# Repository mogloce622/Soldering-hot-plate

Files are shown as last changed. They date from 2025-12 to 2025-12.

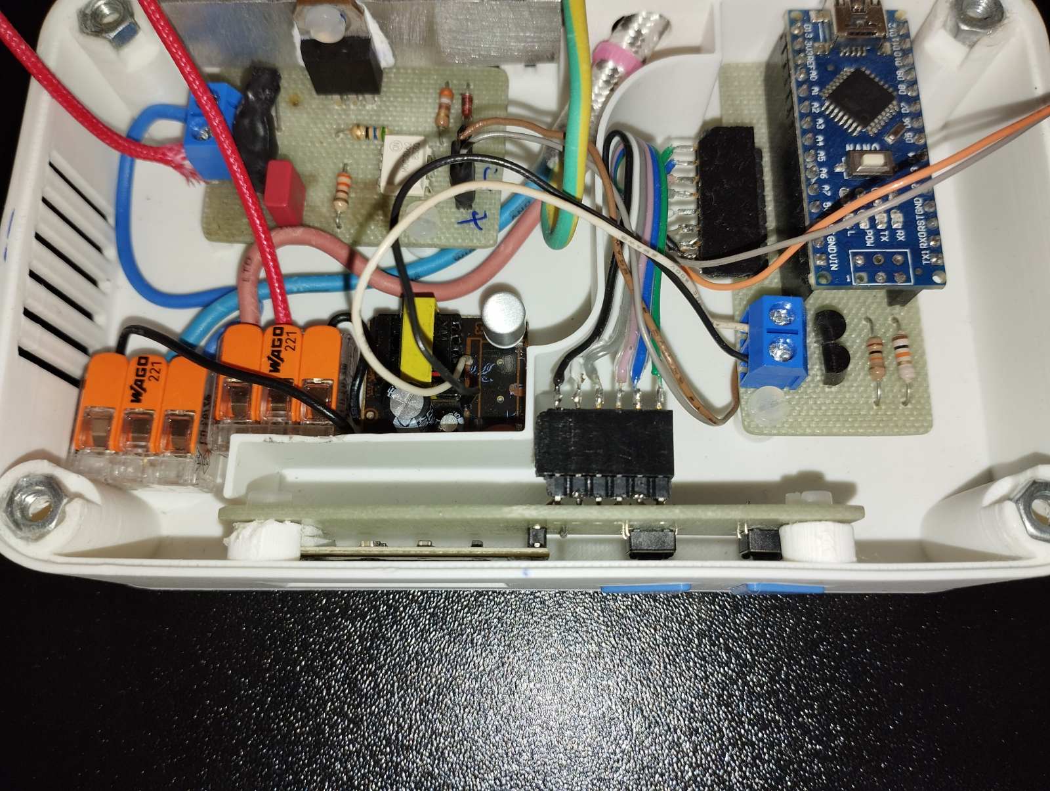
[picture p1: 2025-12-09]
pictures/6.jpg

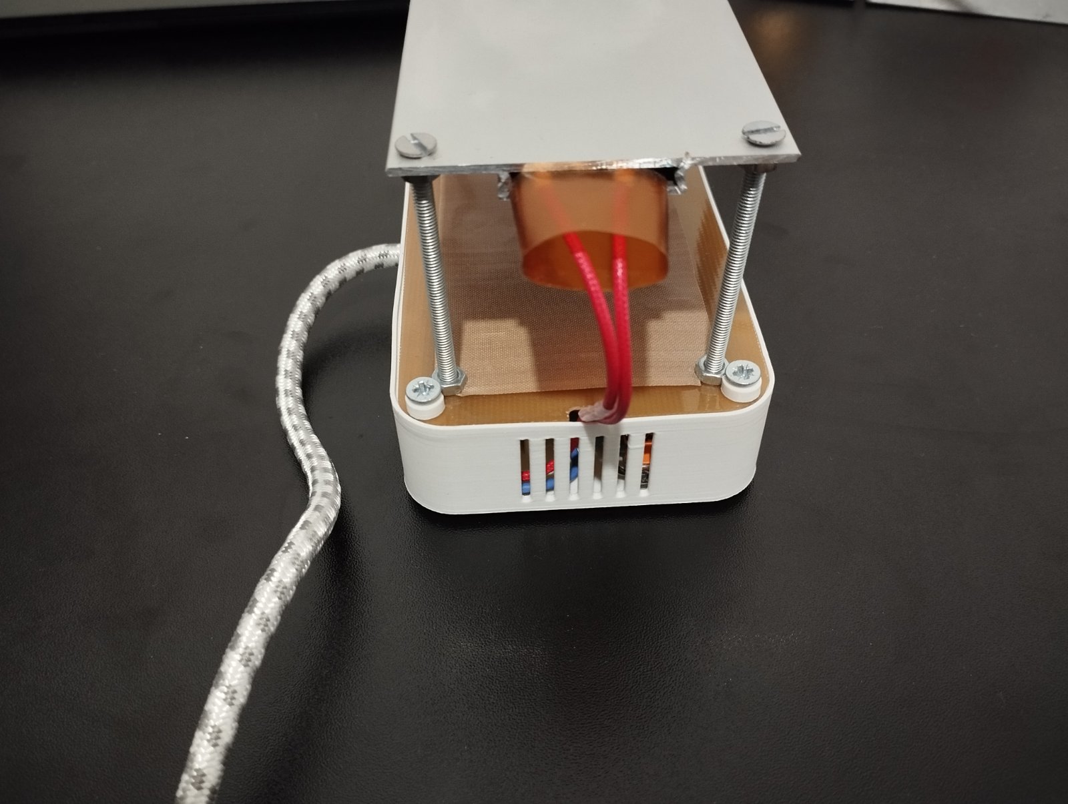
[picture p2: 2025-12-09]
pictures/14.jpg

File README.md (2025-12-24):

This is my hot plate, which has two temperature curves: one for leaded solder paste (183 °C) and one for lead-free paste. It consists of a 400 W 220 V PTC heating plate that is spaced 5.5 cm from the enclosure using screws. The temperature is measured using a 100 k NTC sensor taken from cheap Chinese food thermometers (TP-101). The heating plate is also grounded as shown in the picture and all printed parts are printed using PLA.

If you want buzzer, solder it to pin 8.

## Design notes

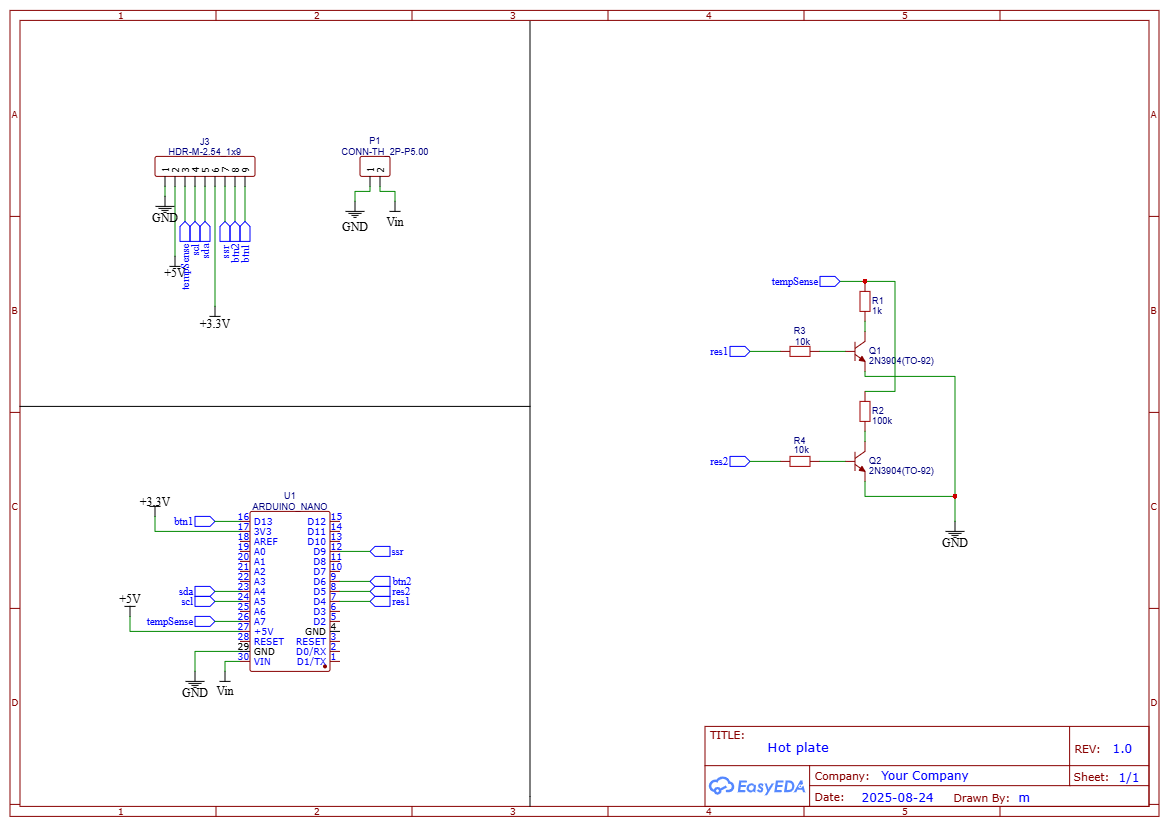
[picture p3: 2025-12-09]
schematic/Hot_plate.png

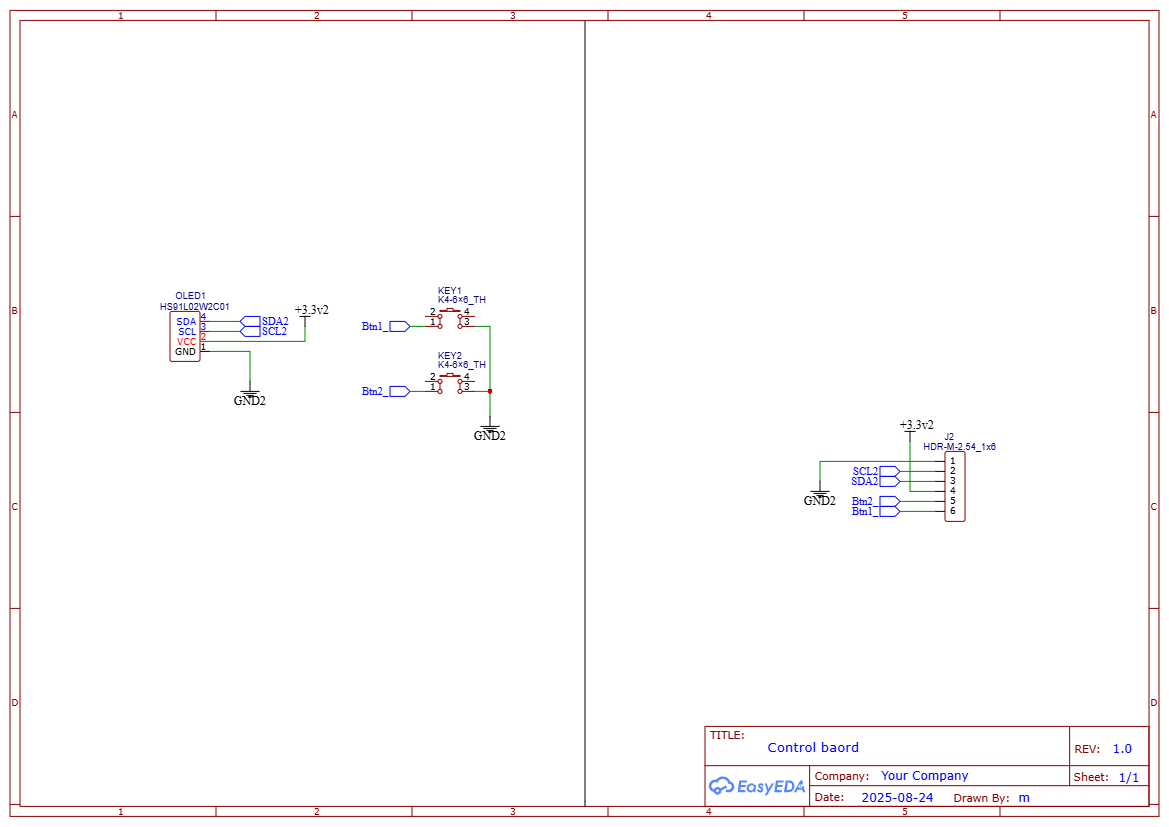
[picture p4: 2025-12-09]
schematic/Control_board.png

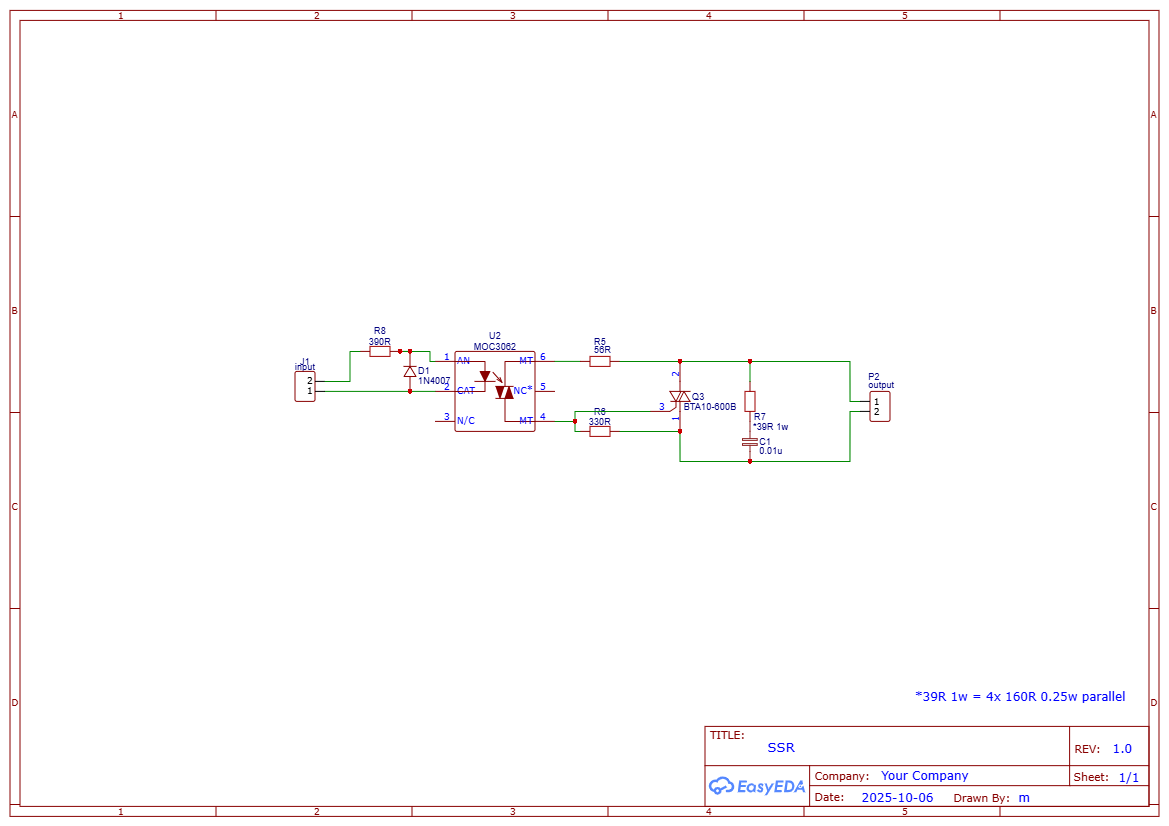
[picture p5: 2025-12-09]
schematic/Ssr.png

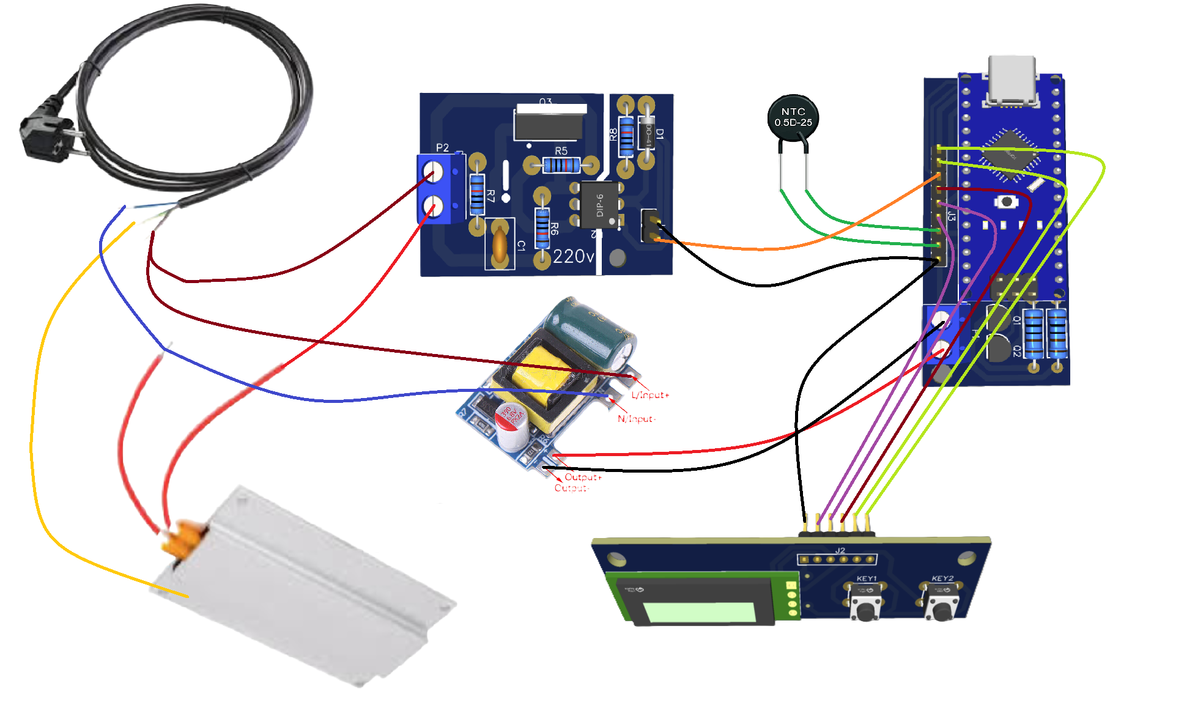
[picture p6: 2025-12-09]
Circuit diagram.png

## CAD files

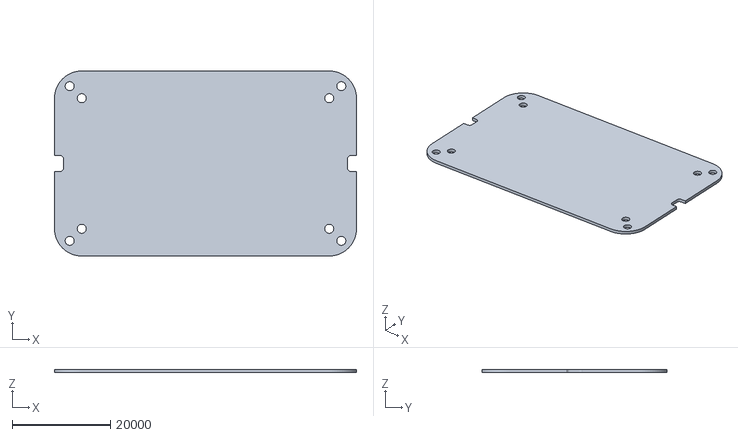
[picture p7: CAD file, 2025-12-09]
3dModels/topCover.dxf
61401.6 x 37625.8 x 692.5

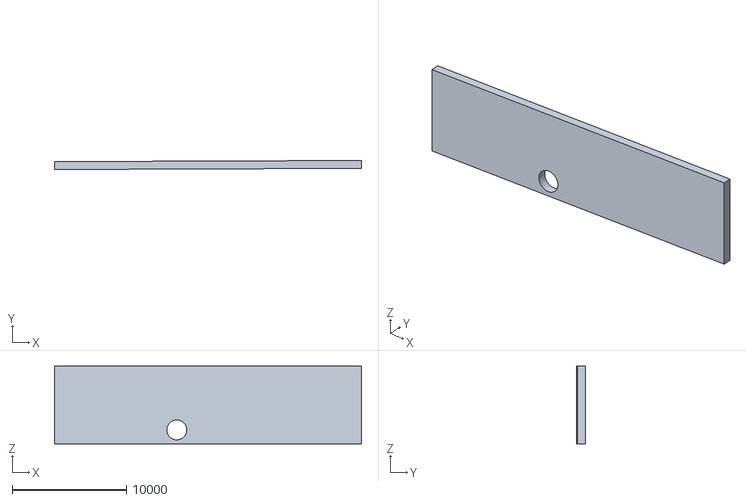
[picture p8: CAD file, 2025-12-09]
3dModels/cooler.dxf
26870.4 x 792.6 x 6823.4

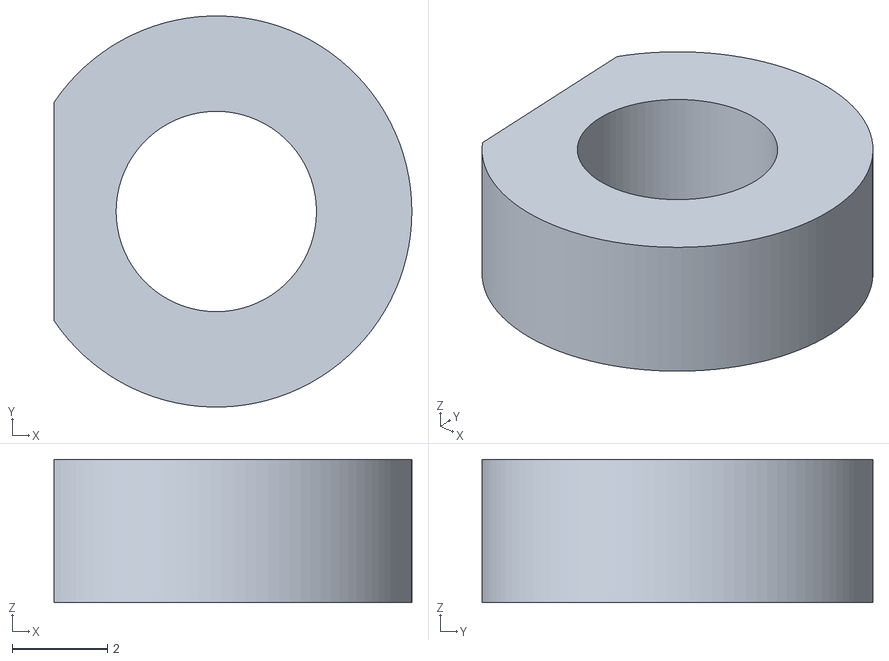
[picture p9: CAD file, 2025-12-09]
3dModels/spacer.stl
7.50 x 8.20 x 3.00

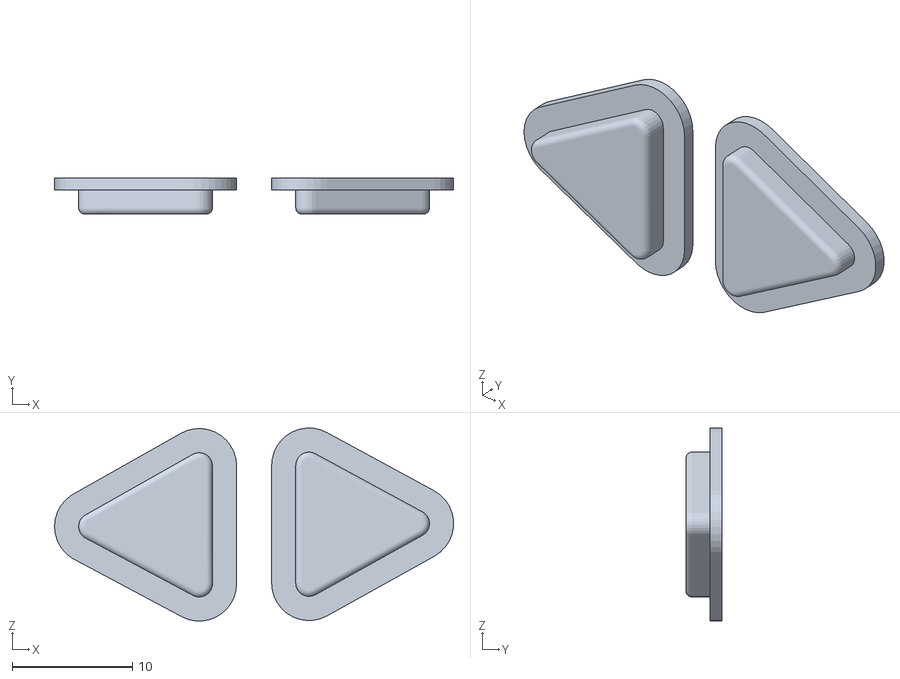
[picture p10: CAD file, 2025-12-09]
3dModels/Hot_plate_buttons.stl
33.1 x 3.00 x 16.0

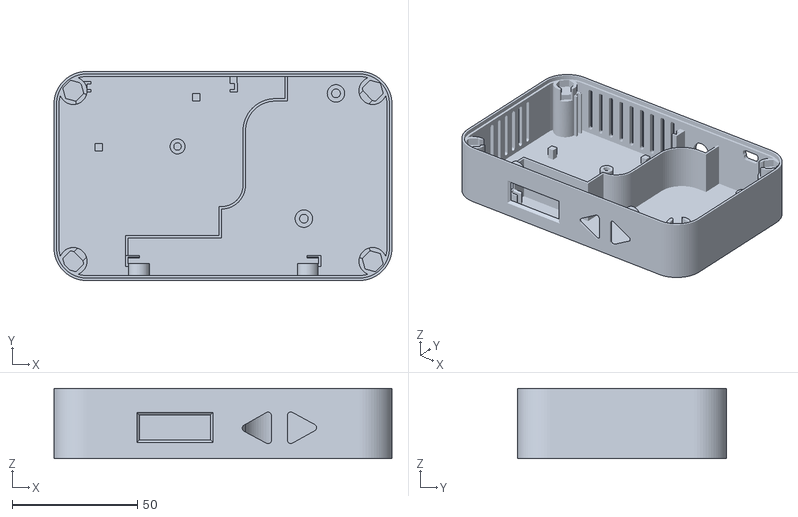
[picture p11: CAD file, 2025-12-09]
3dModels/hot plate.stl
135.0 x 83.5 x 28.0

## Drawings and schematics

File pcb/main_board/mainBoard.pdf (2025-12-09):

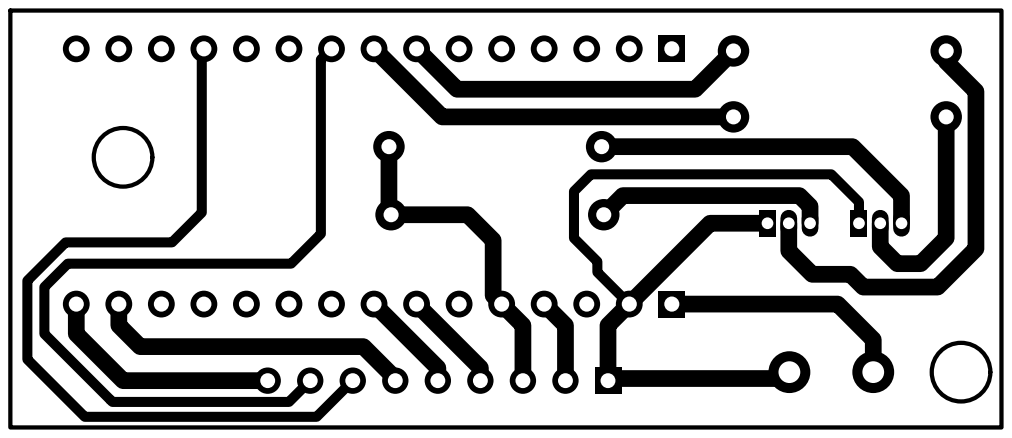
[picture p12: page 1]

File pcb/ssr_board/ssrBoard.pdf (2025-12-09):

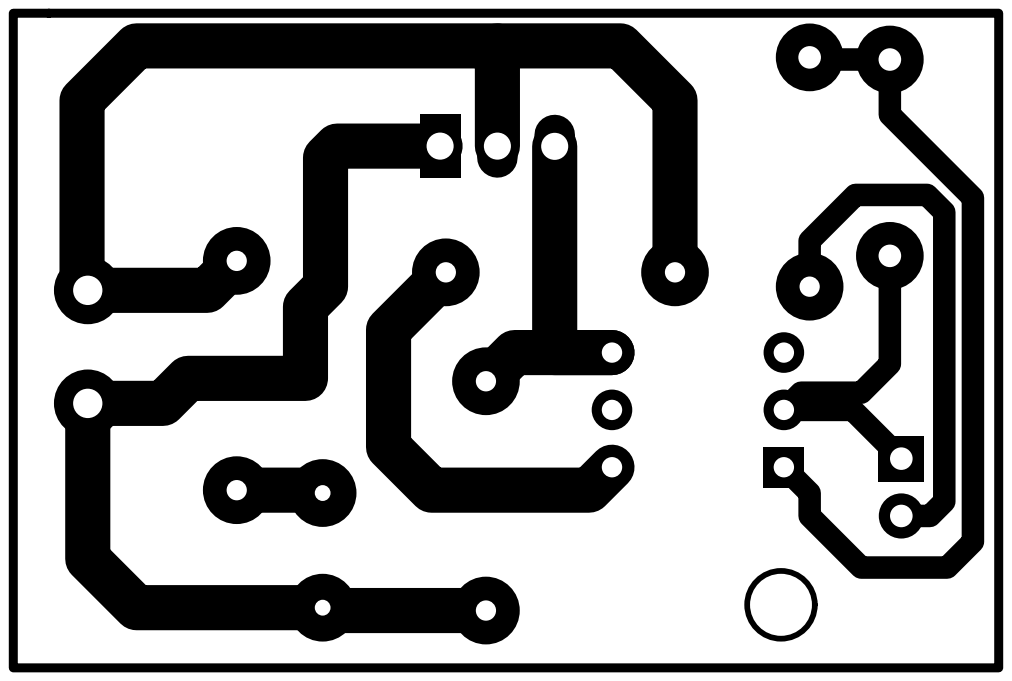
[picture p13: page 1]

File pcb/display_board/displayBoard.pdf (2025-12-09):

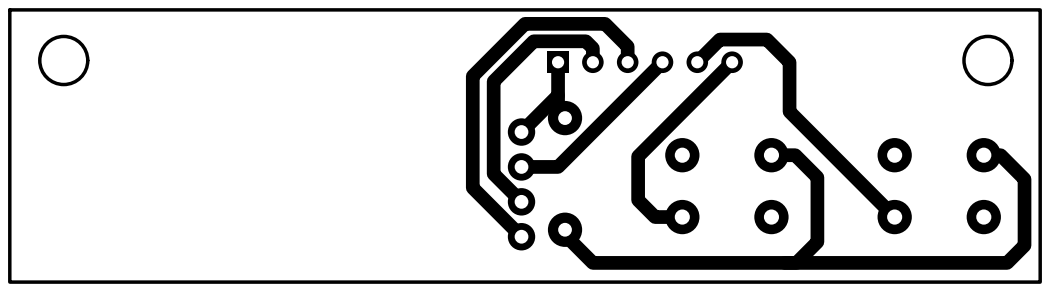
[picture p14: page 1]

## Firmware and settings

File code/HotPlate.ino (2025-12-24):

#include <Wire.h>
#include <Adafruit_GFX.h>
#include <Adafruit_SSD1306.h>
#include <PID_v1.h>
#include "InterpolationLib.h"
#include <Fonts/Org_01.h>
#include "anim.h"

#define SCREEN_WIDTH 128
#define SCREEN_HEIGHT 32
#define OLED_RESET     -1
#define SCREEN_ADDRESS 0x3C

#define temp 7
#define res1 4
#define res2 5
#define plate 9
#define buzzer 8

#define BTN_UP   6
#define BTN_DOWN 13

const double R0 = 100000.0;
const double T0 = 25.0 + 273.15;
const double BETA = 3950.0;
const unsigned long RES1 = 1000;
const unsigned long RES2 = 100000;
double RES = RES1;
static unsigned long lastSwitchTime = 0;
const unsigned long switchCooldown = 500;
const int numValues = 21;
//double tHot[numValues] = { 20.2, 25, 40, 60.2, 80.2, 90, 100, 110, 120, 130, 140, 150, 160, 170, 180, 190, 200, 210, 220, 230, 240 };
//double errorValues[numValues] = { 2.50,  0.50,  0.07, -0.20, -2.10, -2.40, -3.40, -5.07, -3.80, -5.53, -8.53, -9.05, -11.33, -11.75, -15.75, -18.40, -22.24, -24.48, -26.87, -30.75, -31.45 };

unsigned long lastMillis = 0;
const int samples = 40;
int s = 0;
const int thr = 110;
bool wRes = false;
double sumTemp = 0.0;
double sumRes = 0.0;
double avgTemp = 0.0;
double lastTemp = 0.0;
double avgRes = 0.0;
bool finished = false;
int safeTemp = 40;
int heatingState = 0;
int heatingProgress = 0;
bool heated = false;

double setPoint = 0, output = 0;
int mode = 0;
bool menu = false;
unsigned long previousMillis = 0;
int currentFrame = 0;
String modes[3] = {"HEAT", "LEAD", "NOLEAD"};
int modesSize = 3;
int menuPos = 0;
int curveTemp1[] = {145, 165, 225};
int curveTime1[] = {0, 70, 20};
int curveOffset1[] = {10, 0, 10};
int curveTemp2[] = {145, 180, 245};
int curveTime2[] = {0, 60, 15};
int curveOffset2[] = {10, 0, 10};
int arraySize = 3;
int curveStep = 0;
unsigned long holdStart = 0;
bool holding = false;
int targetTemp = 0;
int targetOffset = 0;
bool done = false;
bool ex = false;
bool buz = false;

//pid
double Kp = 4;
double Ki = 0.001;
double Kd = 90;

PID myPID(&avgTemp, &output, &setPoint, Kp, Ki, Kd, DIRECT);
Adafruit_SSD1306 display(SCREEN_WIDTH, SCREEN_HEIGHT, &Wire, OLED_RESET);

void setup() {
  Serial.begin(9600);
  pinMode(temp, INPUT);
  pinMode(res1, OUTPUT);
  pinMode(res2, OUTPUT);
  pinMode(buzzer, OUTPUT);
  digitalWrite(res1, HIGH);
  digitalWrite(res2, LOW);

  pinMode(BTN_UP,   INPUT_PULLUP);
  pinMode(BTN_DOWN, INPUT_PULLUP);

  delay(500);
  if(!display.begin(SSD1306_SWITCHCAPVCC, SCREEN_ADDRESS)) {
    Serial.println(F("SSD1306 allocation failed"));
    for(;;);
  }
  display.setRotation(2);
  display.clearDisplay();
  display.display();
  display.setTextColor(SSD1306_WHITE);
  display.setTextWrap(0);
  display.setFont(&Org_01);
  introAnimation();

  myPID.SetOutputLimits(0, 255);
  myPID.SetSampleTime(1000);
  myPID.SetMode(AUTOMATIC);
}

void loop() {
  unsigned long nowMillis = millis();

  if(buz) {
    digitalWrite(buzzer, HIGH);
    delay(200);
    digitalWrite(buzzer, LOW);
    buz = false;
  }

  //Button 
  String btn = getButtonAction();
  if(mode == 0 && menu == false) {
    if(btn == "up" || btn == "down" || btn == "select") { menu = true; btn = ""; }
  } 
  else if(mode > 0 && menu == false) {
    if(btn == "select") { menu = true; btn = ""; } 
    else if(btn == "exit") { setPoint = 0; targetOffset = 0; heatingState = 1; ex = true; curveStep = 0; }
    if(mode == 1 && menu == false) {
      if(btn == "up") { setPoint += 5; if (setPoint > 250) setPoint = 250; }
      else if(btn == "down") { setPoint -= 5; if (setPoint < 0) setPoint = 0; }
    }
  }

  if(mode > 0 && menu == false) {
    if(avgTemp > 40) heated = true;
    if(avgTemp < setPoint) heatingState = 2;
    else if(avgTemp >= setPoint && heated) heatingState = 1;
    else heatingState = 0;
    if((heated || ex) && avgTemp <= 40) { setPoint = 0; mode = 0; heatingState = 0; heated = false; done = false; holdStart = 0; ex = false; targetOffset = 0; }
  }

  if(menu == true) {
    if(btn == "select") { 
      if(mode != menuPos+1) { 
        setPoint = 0; 
        heated = false;  
        holding = false;
        curveStep = 0; 
        heatingProgress = 0; 
        targetOffset = 0; 
        done = false;
        holdStart = 0;
        ex = false;
        targetOffset = 0;
      } 
      mode = menuPos+1; 
      btn = "exit"; 
    }
    if(btn == "exit") { menu = false; menuPos = 0; }
    else if(btn == "up") { menuPos++; if(menuPos >= modesSize) { menuPos = 0; }}
    else if(btn == "down") { menuPos--; if(menuPos < 0) { menuPos = modesSize-1; }}
  } 

  if (mode > 1 && !done && !ex) {
    int curveTime = 0;
    if(mode == 2) {
      targetTemp = curveTemp1[curveStep];
      targetOffset = curveOffset1[curveStep];
      curveTime = curveTime1[curveStep];
    } else if(mode == 3) {
      targetTemp = curveTemp2[curveStep];
      targetOffset = curveOffset2[curveStep];
      curveTime = curveTime2[curveStep];
    }
    if (!holding) {
      setPoint = targetTemp+targetOffset;
      if (avgTemp >= targetTemp-2) {
        holding = true;
        holdStart = nowMillis;
      }
    }
    else {
      unsigned long holdTime = (unsigned long)curveTime * 1000UL;
      if (nowMillis - holdStart >= holdTime) {
        curveStep++;
        buz = true;
        holding = false;
        if (curveStep >= arraySize) {
          setPoint = 0;
          heatingState = 1;
          curveStep = 0;
          targetOffset = 0;
          done = true;
        }
      }
    }
    heatingProgress = map(curveStep, 0, arraySize, 0, 128);
  }

  static unsigned long lastPrint = 0;
  if (nowMillis - lastPrint >= 5000) {
    lastPrint = nowMillis;
    Serial.print(avgTemp, 1);
    Serial.print(",");
    Serial.println(setPoint, 1);
  }

  if(s < samples) {
    int adcValue = analogRead(temp);
    if (adcValue == 0) adcValue = 1;
    double resistance = RES * ((1023.0 / adcValue) - 1.0);
    double tempK = 1.0 / ( (1.0 / BETA) * log(resistance / R0) + (1.0 / T0) );
    double tempC = tempK - 273.15;
  
    sumTemp += tempC;
    sumRes += resistance;
    s++;
    delayMicroseconds(1000);
  }else finished = true;

  if (finished) {
    avgTemp = sumTemp / samples;
    avgRes  = sumRes / samples;
    if(lastTemp == 0) lastTemp = avgTemp;
    //if(avgTemp < tHot[0]) avgTemp += -0.152028912254266 * avgTemp + 9.81035163281709;
    //else avgTemp += Interpolation::ConstrainedSpline(tHot, errorValues, numValues, avgTemp);

    display.clearDisplay();
    if(menu == false) drawTemp(avgTemp, setPoint-targetOffset, mode, heatingState, heatingProgress);
    else drawMenu();
    display.display();

    sumTemp = 0.0;
    sumRes  = 0.0;
    s = 0;
    finished = false;

    if (nowMillis - lastSwitchTime > switchCooldown) {
      if (avgTemp > (thr + 4) && wRes) {
        digitalWrite(res1, HIGH);
        digitalWrite(res2, LOW);
        RES = RES1; wRes = false;
        lastSwitchTime = nowMillis;
      } else if (avgTemp < (thr - 4) && !wRes) {
        digitalWrite(res1, LOW);
        digitalWrite(res2, HIGH);
        RES = RES2; wRes = true;
        lastSwitchTime = nowMillis;
      }
    }
  }
  if(avgTemp < -50 || analogRead(temp)==0 || lastTemp-avgTemp>10 || lastTemp-avgTemp<-10) {
    display.clearDisplay();
    if(avgTemp < -50) {
      display.setTextSize(5);
      display.setCursor(5, 23);
      display.print("WIRE");
    } else {
      display.setTextSize(3);
      display.setCursor(12, 20);
      display.print("BROKEN");
    }
    display.display();
    for(;;); 
  }
  lastTemp = avgTemp;
  myPID.Compute();
  if (avgTemp > setPoint + 0.5) {
    myPID.SetMode(MANUAL);
    output = 0;
  } else myPID.SetMode(AUTOMATIC);
  analogWrite(plate, (int)output);
}

void drawTemp(double t, double setT, double Mode, int State, int HeatingProgress) {
  static int circleSize = 0;
  if(Mode == 0) { // idle
    display.setTextSize(4);
    display.setCursor(0, 20);
    display.print(String(t,1));
  } else if (Mode > 0) {
    display.setTextSize(3);
    display.setCursor(0, 14);
    display.print(String(t,1));
    display.setTextSize(2);
    display.setCursor(0, 28);
    display.print(String(setT,1));
    unsigned long currentMillis = millis();
    if(State == 1) { //cooling
      if (currentMillis - previousMillis >= FRAME_DELAY) {
        previousMillis = currentMillis;
        display.drawBitmap(HOURGLASS_X, HOURGLASS_Y, frames[currentFrame], FRAME_WIDTH, FRAME_HEIGHT, WHITE);
        currentFrame = (currentFrame + 1) % FRAME_COUNT;
      } 
    } else if(State == 2) { //heating
      if (currentMillis - previousMillis >= FRAME_DELAY) {
        previousMillis = currentMillis;
        display.drawBitmap(HOURGLASS_X, HOURGLASS_Y, frames1[currentFrame], FRAME_WIDTH, FRAME_HEIGHT, WHITE);
        currentFrame = (currentFrame + 1) % FRAME_COUNT1;
      }
    }
    if(Mode > 1) {
      display.drawLine(0, 31, HeatingProgress, 31, 1);
      display.fillRoundRect(HeatingProgress-10, 28, 12, 7, 2, 0);
      display.fillRoundRect(HeatingProgress-9, 29, 10, 6, 2, 1);
    }
  }
}
void drawMenu() {
  for(int i = 2;i<32;i+=2) display.writePixel(124, i, 1);
  display.fillRect(123, 32/modesSize*(menuPos), 3, 10, 1);
  display.setTextSize(3);
  display.setCursor(10, 20);
  display.print(modes[menuPos]);
  display.drawLine(5, 27, 5, 3, 1);
}
void introAnimation() {
  display.clearDisplay();
  randomSeed(millis());

  const int SIZE = 4;
  const int COLS = 128 / SIZE;
  const int ROWS = 32  / SIZE;
  int pos = 0;
  int m = 0;

  while (pos <= 150) {
    for(int j = 0; j<4;j++) {
      int col = random(COLS);
      int row = random(ROWS);
      int x = col * SIZE;
      int y = row * SIZE;
      if (display.getPixel(x + SIZE/2, y + SIZE/2) == 0) {
        display.fillRect(x+1, y+1, SIZE-1, SIZE-1, WHITE);
      }
    }
    m++;
    if(m > 30) {
      for(int i = 0; i<pos; i++) {
        int inv_i = 128-i;
        display.drawLine(inv_i+8, 0, inv_i, 16, 0);
        display.drawLine(inv_i+8, 32, inv_i, 16, 0);
      }
      pos+=3;
      int real_pos = 132-pos;
      for(int k = 0;k<3;k++) {
        display.drawLine(real_pos+8+k, 0, real_pos+k, 16, 1);
        display.drawLine(real_pos+8+k, 32, real_pos+k, 16, 1);
      }
      for(int k = 0;k<1;k++) {
        display.drawLine(real_pos+15+k, 3, real_pos+8+k, 16, 1);
        display.drawLine(real_pos+15+k, 29, real_pos+8+k, 16, 1);
      }
    }
    display.display();
  }
  display.clearDisplay();
  display.setTextSize(2);
  display.setCursor(10, 19);
  display.print("HOT PLATE");
  display.display();
  delay(800);
  display.clearDisplay();
  display.display();
}

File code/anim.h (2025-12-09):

#define HOURGLASS_X     (SCREEN_WIDTH - FRAME_WIDTH)
#define HOURGLASS_Y     0

#define FRAME_DELAY (42) 
#define FRAME_WIDTH (32)
#define FRAME_HEIGHT (32)

#define FRAME_COUNT (sizeof(frames) / sizeof(frames[0]))
const byte PROGMEM frames[][128] = {
  {0,0,3,0,0,0,3,0,0,0,7,0,0,32,59,112,0,32,31,224,0,32,7,160,3,44,7,160,1,248,27,224,0,112,59,112,1,252,7,0,3,38,3,0,0,32,3,0,0,32,0,0,0,0,0,0,0,0,0,0,0,0,0,0,12,0,0,0,45,0,0,0,31,0,0,0,30,0,0,0,63,0,0,0,12,0,0,16,4,0,0,28,0,0,0,56,0,8,0,8,0,8,12,0,0,126,7,0,0,28,14,0,0,126,30,0,0,74,2,0,0,8,0,0,0,0,0,0},
  {0,0,1,0,0,0,3,0,0,0,11,128,0,48,57,112,0,48,31,112,3,32,7,224,1,166,63,128,0,120,59,224,0,240,58,96,3,188,7,64,2,38,3,0,0,32,2,0,0,32,0,0,0,0,0,0,0,0,0,0,4,0,0,0,36,0,0,0,63,0,0,0,14,0,0,0,62,0,0,0,47,0,0,0,8,0,0,16,0,0,0,24,0,0,0,60,0,24,0,56,0,88,8,0,0,62,12,0,0,56,15,0,0,252,28,0,0,16,4,0,0,16,0,0,0,0,0,0},
  {0,0,0,0,0,0,1,128,0,0,29,192,0,12,29,128,0,136,7,48,0,88,55,240,0,123,63,176,0,255,51,128,3,248,6,224,0,44,14,224,0,36,6,0,0,98,0,0,0,0,0,0,0,0,0,0,6,0,0,0,52,0,0,0,28,0,0,0,63,0,0,0,62,0,0,0,14,0,0,0,26,0,0,0,0,0,0,0,0,0,0,0,0,16,0,48,0,208,0,120,0,112,8,48,0,124,24,0,1,240,62,0,0,120,60,0,0,72,8,0,0,0,8,0,0,0,0,0},
  {0,0,0,0,0,0,0,0,0,2,0,192,0,102,13,192,0,52,12,144,0,31,206,184,0,15,3,248,0,126,31,192,0,79,61,240,0,8,137,48,0,8,3,48,0,0,3,128,4,0,0,0,60,0,0,0,31,0,0,0,60,0,0,0,110,0,0,0,26,0,0,0,0,0,0,0,0,0,0,0,0,0,0,0,0,0,0,0,0,128,0,0,6,128,0,0,3,240,0,0,3,192,1,128,7,192,0,192,1,97,177,192,1,0,224,0,0,0,224,0,0,1,32,0,0,0,0,0},
  {0,0,0,0,0,0,0,0,0,36,0,0,0,28,0,0,0,31,0,0,0,124,0,64,0,30,12,64,0,18,6,192,0,0,3,128,36,0,3,248,52,0,31,128,31,0,1,192,126,0,3,96,28,0,2,32,22,0,2,0,16,0,0,0,0,0,0,0,0,0,0,0,0,0,4,96,0,0,7,112,36,0,7,96,60,0,1,200,28,0,13,252,18,0,31,236,16,0,12,224,0,0,1,184,0,64,3,176,1,192,3,136,0,224,0,0,0,160,0,0,0,0,0,0,0,0,0,0},
  {0,0,0,0,0,0,0,0,0,0,2,0,0,1,2,0,0,3,207,192,0,1,139,0,0,1,3,0,0,0,0,0,2,0,0,0,70,0,0,0,119,0,0,72,118,0,0,120,28,192,0,62,223,192,0,248,254,0,0,60,202,128,0,36,27,128,0,32,59,128,0,0,16,0,0,0,0,0,0,0,0,2,0,64,0,102,3,192,0,52,1,240,0,28,3,224,0,31,135,192,0,252,1,96,0,30,1,0,0,27,0,0,0,17,0,0,0,16,0,0,0,0,0,0,0,0,0,0},
  {0,3,112,0,0,7,112,0,0,3,112,0,0,9,200,0,0,31,252,0,0,9,220,0,0,1,64,0,0,7,112,0,4,7,96,0,4,68,32,0,2,192,0,0,3,128,0,0,63,240,0,0,3,240,0,0,2,128,0,14,6,192,0,14,4,64,0,4,0,0,0,0,0,0,0,0,0,0,0,0,0,0,0,96,1,32,0,56,0,224,0,240,7,240,0,176,1,240,72,16,1,192,120,0,1,33,252,0,0,0,124,0,0,0,112,0,0,0,72,0,0,0,0,0,0,0,0,0},
  {0,0,24,0,0,1,92,0,0,1,219,128,0,1,255,0,0,0,61,0,0,129,252,0,0,129,215,0,8,129,147,128,14,152,56,0,3,240,16,0,1,192,16,0,7,224,0,0,12,184,0,0,0,128,0,0,0,128,0,0,0,0,0,0,0,0,0,0,0,0,0,4,2,0,0,14,2,0,0,15,31,192,0,4,7,0,0,0,15,128,0,0,26,192,0,64,2,0,3,192,0,1,1,240,0,7,224,128,0,3,192,128,0,7,192,0,0,5,96,0,0,1,0,0,0,0,0,0},
  {0,0,12,0,0,0,14,0,0,0,12,192,0,0,36,192,0,192,119,64,0,192,63,0,0,88,15,224,7,112,58,96,1,224,51,0,0,248,55,0,1,236,3,0,3,32,0,0,0,32,0,0,0,32,0,0,0,0,0,0,0,0,0,0,8,0,0,0,13,0,0,0,7,0,0,0,30,0,0,0,15,128,0,16,28,0,0,28,6,0,0,28,0,0,0,4,0,8,0,0,0,9,4,128,0,62,7,0,0,30,7,0,0,31,9,0,0,52,0,0,0,4,0,0,0,0,0,0},
  {0,0,2,0,0,0,3,0,0,0,7,64,0,32,58,112,0,96,59,224,0,96,7,128,3,108,7,160,1,248,63,224,0,112,59,112,1,248,7,0,3,38,3,0,0,32,2,0,0,32,0,0,0,0,0,0,0,0,0,0,0,0,0,0,12,0,0,0,45,0,0,0,63,0,0,0,30,0,0,0,63,0,0,0,4,0,0,16,4,0,0,28,0,0,0,56,0,8,0,8,0,10,12,0,0,126,7,0,0,28,14,0,0,62,30,0,0,72,2,0,0,8,0,0,0,0,0,0}
}; // fire

#define FRAME_COUNT1 (sizeof(frames1) / sizeof(frames1[0]))
const byte PROGMEM frames1[][128] = {
  {0,6,0,0,0,7,0,0,0,5,192,0,0,4,96,0,0,12,48,0,0,8,24,0,0,24,12,0,0,48,6,0,0,32,3,0,0,96,1,128,0,192,128,192,1,128,192,64,1,0,224,96,3,0,176,32,6,0,216,48,4,0,140,16,12,0,132,24,8,16,132,8,24,57,134,8,16,47,6,8,16,96,6,8,16,64,6,8,16,64,4,8,16,96,12,8,16,32,12,24,24,48,24,16,8,8,16,16,12,0,0,32,6,0,0,96,3,0,0,192,1,224,3,128,0,120,2,0},
  {0,0,0,0,0,0,0,0,0,24,0,0,0,28,0,0,0,51,0,0,0,33,128,0,0,96,192,0,0,64,96,0,0,192,48,0,1,128,12,0,1,0,6,0,3,6,3,0,2,3,1,128,4,3,128,128,12,2,96,192,8,2,32,96,24,2,16,32,16,98,24,48,16,126,8,48,48,92,12,16,32,192,12,16,32,192,12,16,32,192,12,16,32,64,8,16,48,96,8,16,48,48,16,16,16,8,16,32,24,0,0,96,12,0,0,64,6,0,1,192,1,192,3,0,0,240,6,0},
  {0,0,0,0,0,0,0,0,0,64,0,0,0,96,0,0,0,240,0,0,1,156,0,0,1,6,0,0,3,3,128,0,2,0,224,0,6,0,48,0,12,16,28,0,8,24,6,0,24,30,3,0,16,11,1,128,16,9,129,128,48,8,192,192,32,152,32,64,32,240,16,96,97,128,24,96,97,128,8,32,97,128,8,32,96,128,8,32,96,128,24,32,96,64,16,32,32,48,48,32,48,28,32,64,48,0,0,64,24,0,0,192,12,0,1,128,3,128,7,0,0,224,12,0},
  {0,0,0,0,0,1,0,0,0,3,192,0,0,2,96,0,0,6,48,0,0,4,24,0,0,12,6,0,0,8,2,0,0,24,1,0,0,48,0,128,0,96,0,192,0,64,96,96,0,128,112,32,1,128,112,48,3,0,104,16,2,0,108,24,4,0,100,8,12,8,68,8,8,28,70,8,8,19,130,8,24,48,2,12,16,32,6,12,16,32,6,8,24,32,4,8,24,48,12,8,24,24,24,24,8,8,16,16,12,0,0,48,6,0,0,96,3,0,0,192,0,224,1,128,0,120,3,0},
  {0,0,0,0,0,0,192,0,0,1,224,0,0,1,48,0,0,3,12,0,0,2,6,0,0,6,3,0,0,12,1,128,0,24,0,128,0,16,0,64,0,32,48,32,0,64,48,32,0,128,56,16,1,128,60,16,3,0,52,8,2,0,54,8,4,0,38,8,4,6,34,12,8,11,226,12,8,24,2,4,8,16,2,4,8,16,2,12,8,16,6,12,8,24,12,8,8,8,24,24,12,12,16,16,6,0,0,48,2,0,0,96,3,128,0,192,0,224,3,128,0,56,2,0},
  {0,6,0,0,0,7,0,0,0,5,192,0,0,4,96,0,0,12,48,0,0,8,24,0,0,24,12,0,0,48,6,0,0,32,3,0,0,96,1,128,0,192,128,192,1,128,192,64,1,0,224,96,3,0,176,32,6,0,216,48,4,0,140,16,12,0,132,24,8,16,132,8,24,57,134,8,16,47,6,8,16,96,6,8,16,64,6,8,16,64,4,8,16,96,12,8,16,32,12,24,24,48,24,16,8,8,16,16,12,0,0,32,6,0,0,96,3,0,0,192,1,224,3,128,0,120,2,0},
  {0,0,0,0,0,24,0,0,0,28,0,0,0,19,0,0,0,49,128,0,0,32,192,0,0,96,96,0,0,192,16,0,0,128,12,0,1,128,6,0,1,2,3,0,2,3,1,0,6,3,128,128,4,3,192,64,12,3,96,96,8,3,48,32,24,3,16,48,16,98,24,16,48,118,8,16,48,92,12,16,32,192,12,24,32,192,12,24,32,64,12,24,48,64,8,24,48,96,24,16,16,48,24,16,16,8,16,48,8,0,0,32,12,0,0,96,7,0,0,192,1,192,3,128,0,112,6,0},
  {0,0,0,0,0,128,0,0,0,192,0,0,1,224,0,0,3,24,0,0,2,12,0,0,6,7,0,0,4,1,128,0,8,0,96,0,24,0,48,0,16,48,12,0,48,56,6,0,32,30,3,0,32,19,1,128,32,17,128,128,96,16,192,192,67,176,96,96,67,224,48,32,67,0,16,32,65,0,24,32,65,0,8,32,65,128,8,32,64,128,24,32,96,192,16,32,96,112,48,32,32,24,32,96,48,0,0,64,24,0,0,192,14,0,1,128,3,192,7,0,0,224,4,0},
  {0,0,0,0,0,0,0,0,0,0,48,0,0,0,120,0,0,0,204,0,0,0,131,0,0,1,129,128,0,3,0,192,0,6,0,64,0,12,0,32,0,24,0,48,0,48,12,16,0,96,12,8,0,192,6,8,0,128,6,12,1,128,5,4,1,1,141,4,3,2,217,4,2,4,113,6,6,12,1,2,6,8,1,2,4,8,1,6,4,8,3,6,6,8,6,4,6,12,12,4,2,4,24,8,3,0,0,24,1,0,0,48,0,192,0,96,0,112,1,128,0,28,3,0},
  {0,0,0,0,0,3,0,0,0,3,192,0,0,2,96,0,0,6,48,0,0,4,24,0,0,12,6,0,0,24,2,0,0,16,3,0,0,32,1,128,0,96,64,192,0,192,96,96,1,128,112,32,1,0,112,48,2,0,72,16,6,0,72,24,4,0,68,8,12,24,68,8,8,28,194,8,8,51,130,12,24,32,2,12,16,32,6,12,16,32,6,8,24,32,4,8,24,48,12,8,8,16,8,24,12,8,16,16,4,0,0,48,6,0,0,96,3,128,0,192,0,224,1,128,0,120,2,0}
}; // freze

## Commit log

2025-12-09 Material: aluminium
    [cooler.dxf]
2025-12-09 Material: FR4 board without copper
    [topCover.dxf]
